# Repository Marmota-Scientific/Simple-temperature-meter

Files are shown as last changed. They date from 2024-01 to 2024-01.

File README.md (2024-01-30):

# Simple temperature meter

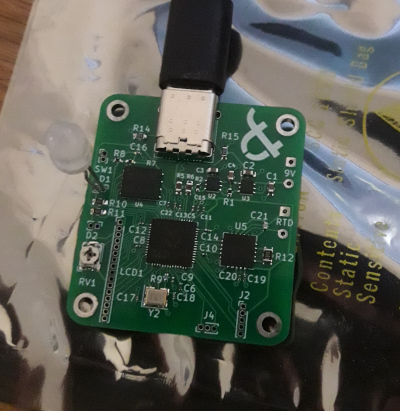
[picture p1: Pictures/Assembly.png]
1st prototype


A simple 15-bit digital temperature meter capable of reading temperatures ranging from –200C to 500C (dependent on reference resistor and used probe). The meter is designed to work with platinum resistance temperature detectors PT100 and PT1000, which are converted into digital values with the usage of a MAX31865 ADC with a nominal temperature resolution of 0.03125C over full range.  

### Connectivity  

- USB 1.1 USB C  

- Handles programming and data output

### User interface

- 2 x 16 character LCD display
- 2 LEDs for user adjustable temperature level alarms  
- Rotary encoder with button  

### Power supply

- Designed to work on a 9V battery
- Operational input voltage level 18V – 5V  
- TPS7A26 linear voltage regulator

### ADC

- MAX31865 15-Bit ADC

### MCU

- RP2040 MCU
- 12 MHz clock speed

## Revision history

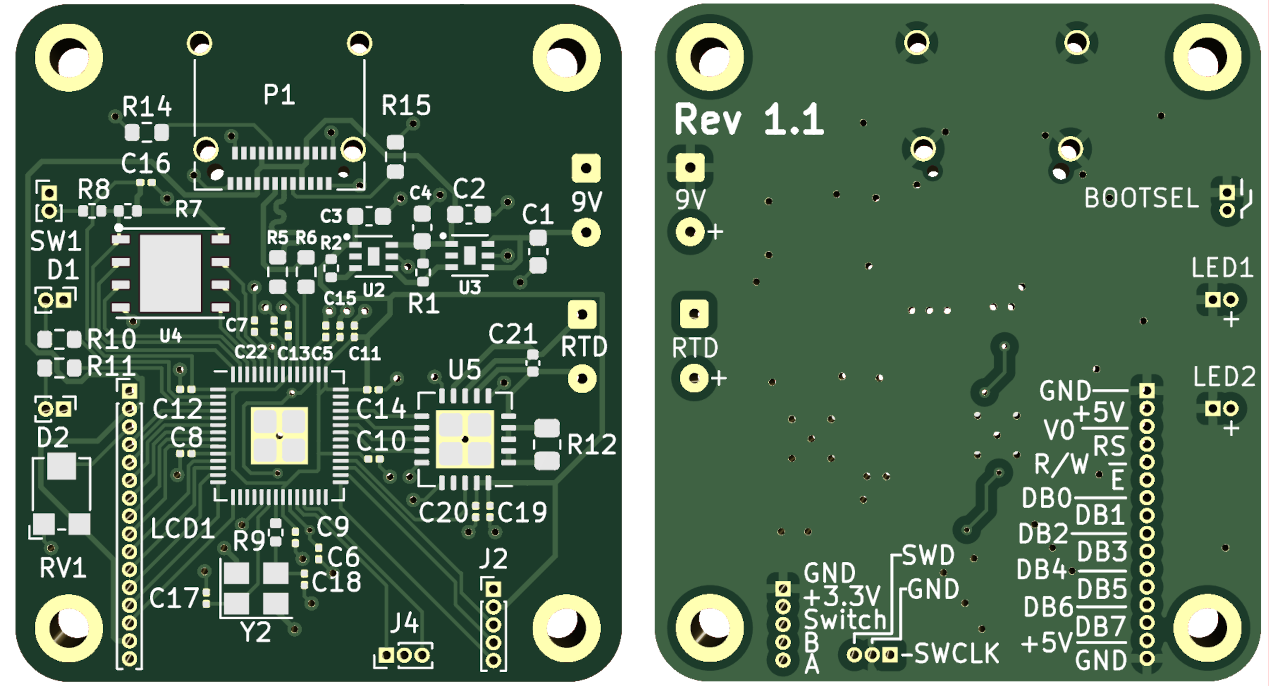
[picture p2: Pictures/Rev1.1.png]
Rev 1.1


- The first working prototype
- Focus on compact sizing over all

### Revision 2.X

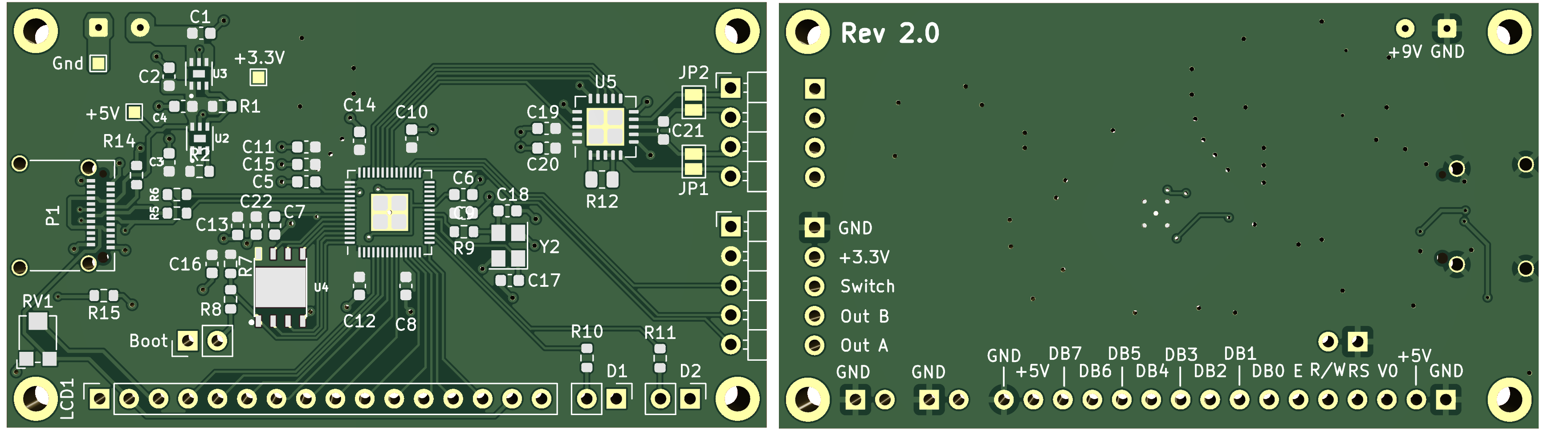
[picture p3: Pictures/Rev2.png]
Rev 2.0


- Focus shifted to ease of construction
- Board dimensions and mounting holes match screen spesification

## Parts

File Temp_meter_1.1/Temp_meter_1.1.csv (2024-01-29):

Id | Designator | Footprint | Quantity | Designation | Supplier and ref
1 | H4,H1,H2,H3 | MountingHole_2.2mm_M2_DIN965_Pad | 4 | MountingHole
2 | C3,C2,C1,C4 | C_0603_1608Metric | 4 | 1µF
3 | C7,C8,C20,C13,C22,C11,C10,C16,C14,C6,C9,C19,C12 | C_0201_0603Metric | 13 | 0.1µF
4 | R5,R6 | R_0603_1608Metric | 2 | 27
5 | R9 | R_0402_1005Metric | 1 | 2k
6 | J2 | PinHeader_1x05_P1.00mm_Vertical | 1 | Rotary encoder
7 | C5,C15 | C_0201_0603Metric | 2 | 1µF
8 | R11,R10 | R_0603_1608Metric | 2 | 330
9 | D1,D2 | PinHeader_1x02_P1.00mm_Vertical | 2 | LED
10 | R14,R15 | R_0603_1608Metric | 2 | 5.1k
11 | R7,R1,R2 | R_0402_1005Metric | 3 | 10k
12 | C17,C18 | C_0201_0603Metric | 2 | 6pF
13 | J1 | SolderWire-0.1sqmm_1x02_P3.6mm_D0.4mm_OD1mm | 1 | 9V in
14 | U5 | TQFN-20-1EP_5x5mm_P0.65mm_EP3.25x3.25mm | 1 | MAX31865xTP
15 | J3 | SolderWire-0.1sqmm_1x02_P3.6mm_D0.4mm_OD1mm | 1 | RTD connector
16 | U4 | SON127P610X510X80-8N430X340 | 1 | W25Q128JVPIQ
17 | LCD1 | PinHeader_1x16_P1.00mm_Vertical | 1 | MC10811A6W
18 | R12 | R_0805_2012Metric | 1 | 1.5k
19 | P1 | USB_C_Receptacle_Amphenol_12401610E4-2A_CircularHoles | 1 | USB_C_Plug_USB2.0
20 | Y2 | Crystal_SMD_3225-4Pin_3.2x2.5mm | 1 | Crystal_GND24
21 | SW1 | PinHeader_1x02_P1.00mm_Vertical | 1 | SW_DIP_x01
22 | U2 | SON65P200X200X80-7N | 1 | TPS7A2633DRVR
23 | R8 | R_0402_1005Metric | 1 | 1k
24 | J4 | PinHeader_1x03_P1.00mm_Vertical | 1 | Debug
25 | U3 | SON65P200X200X80-7N | 1 | TPS7A2650DRVR
26 | C21 | C_0402_1005Metric | 1 | 10nF
27 | RV1 | Potentiometer_Bourns_TC33X_Vertical | 1 | 20k
28 | U1 | QFN-56-1EP_7x7mm_P0.4mm_EP3.2x3.2mm | 1 | RP2040

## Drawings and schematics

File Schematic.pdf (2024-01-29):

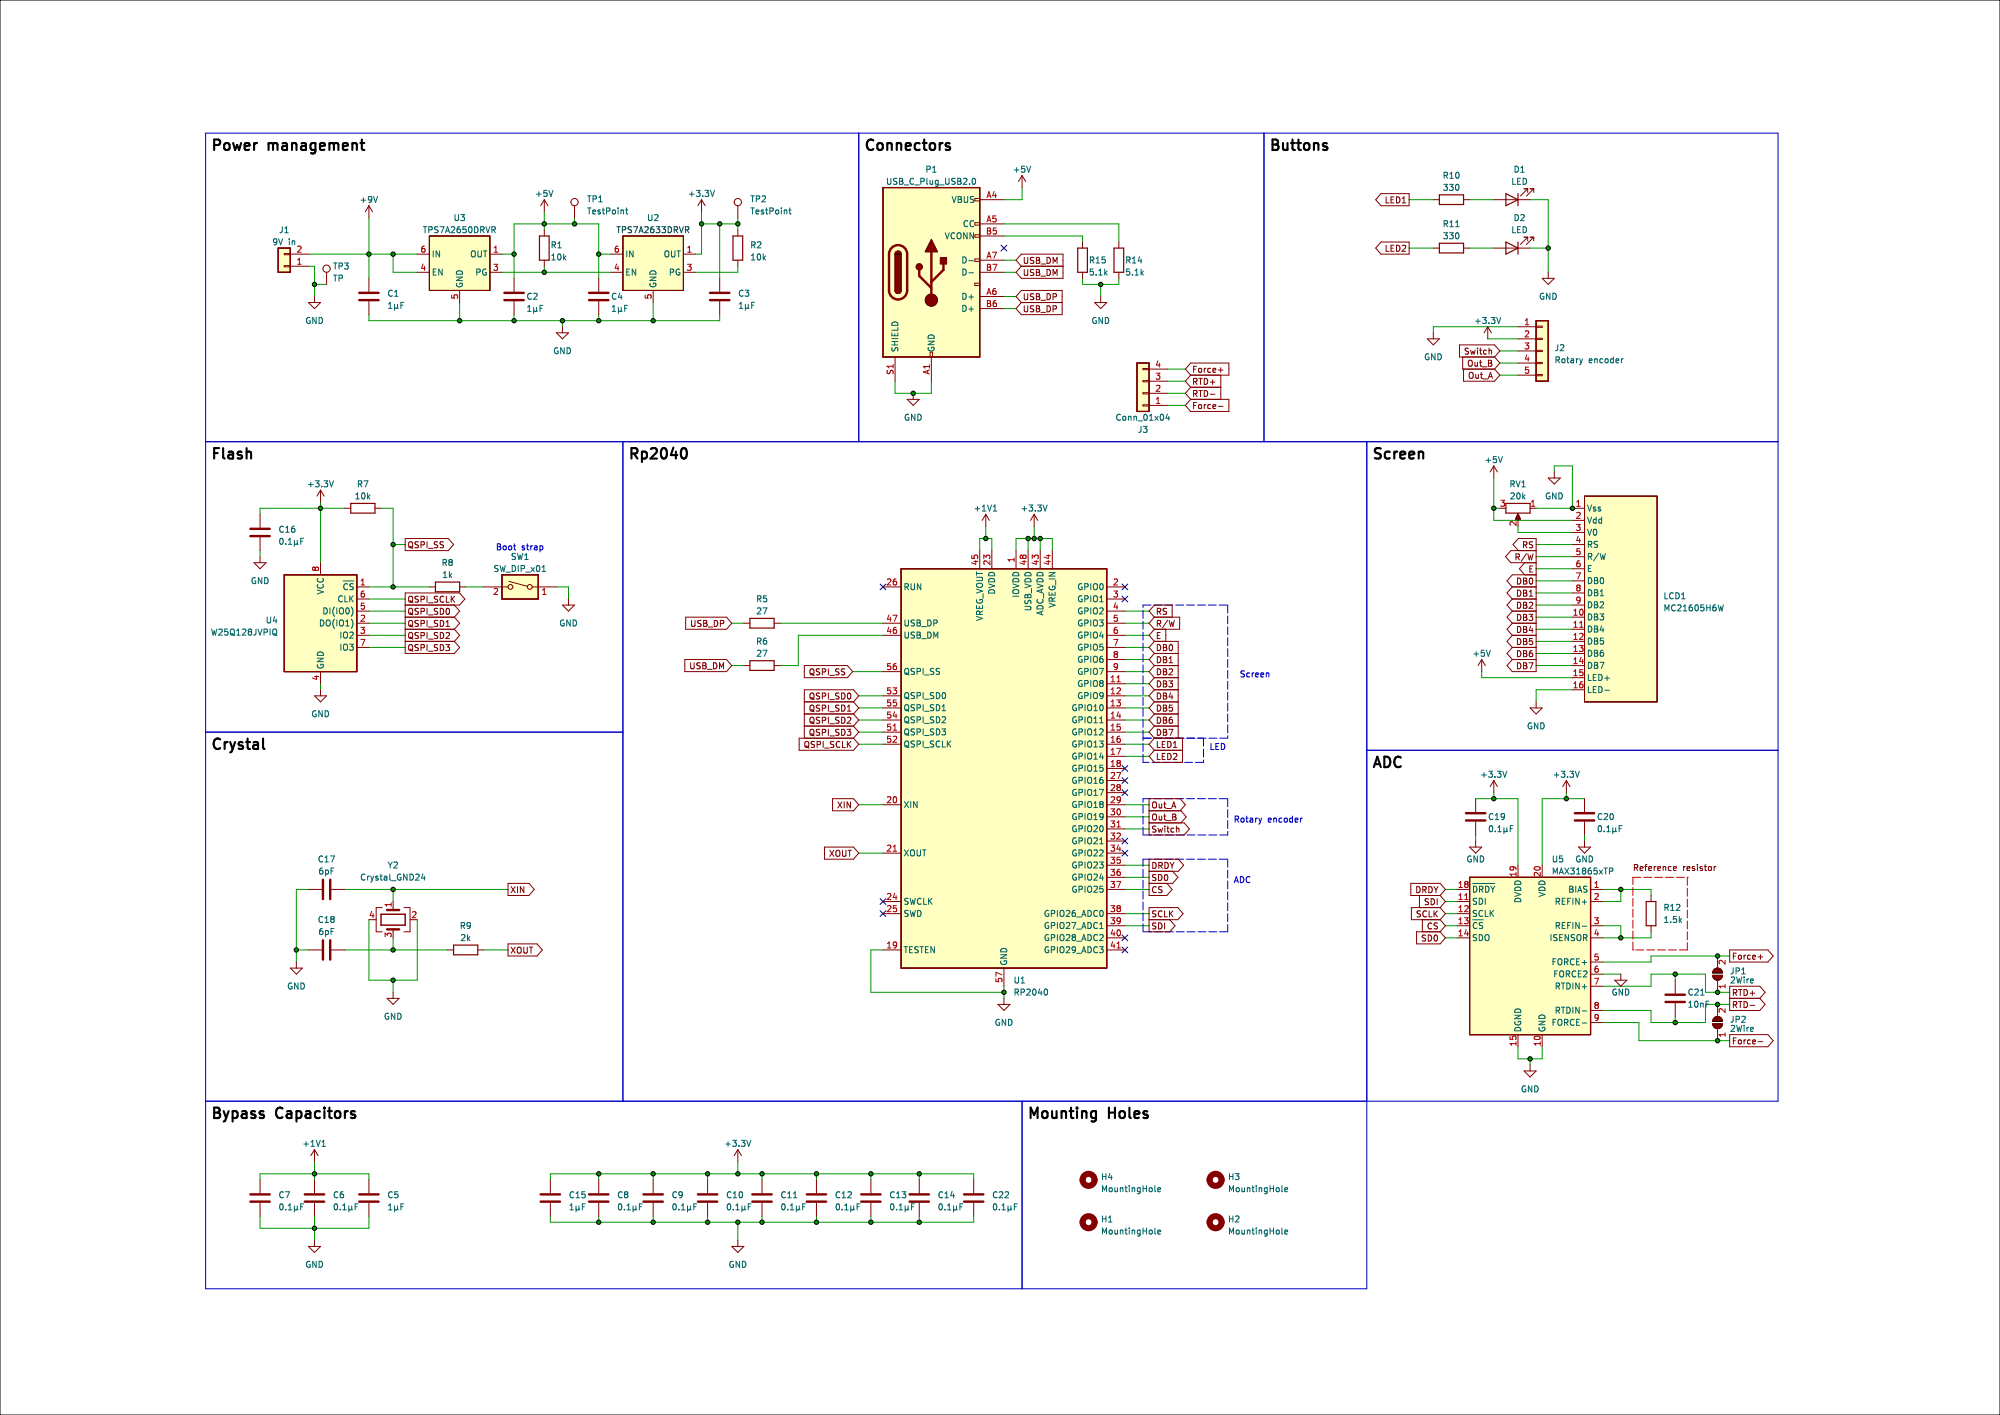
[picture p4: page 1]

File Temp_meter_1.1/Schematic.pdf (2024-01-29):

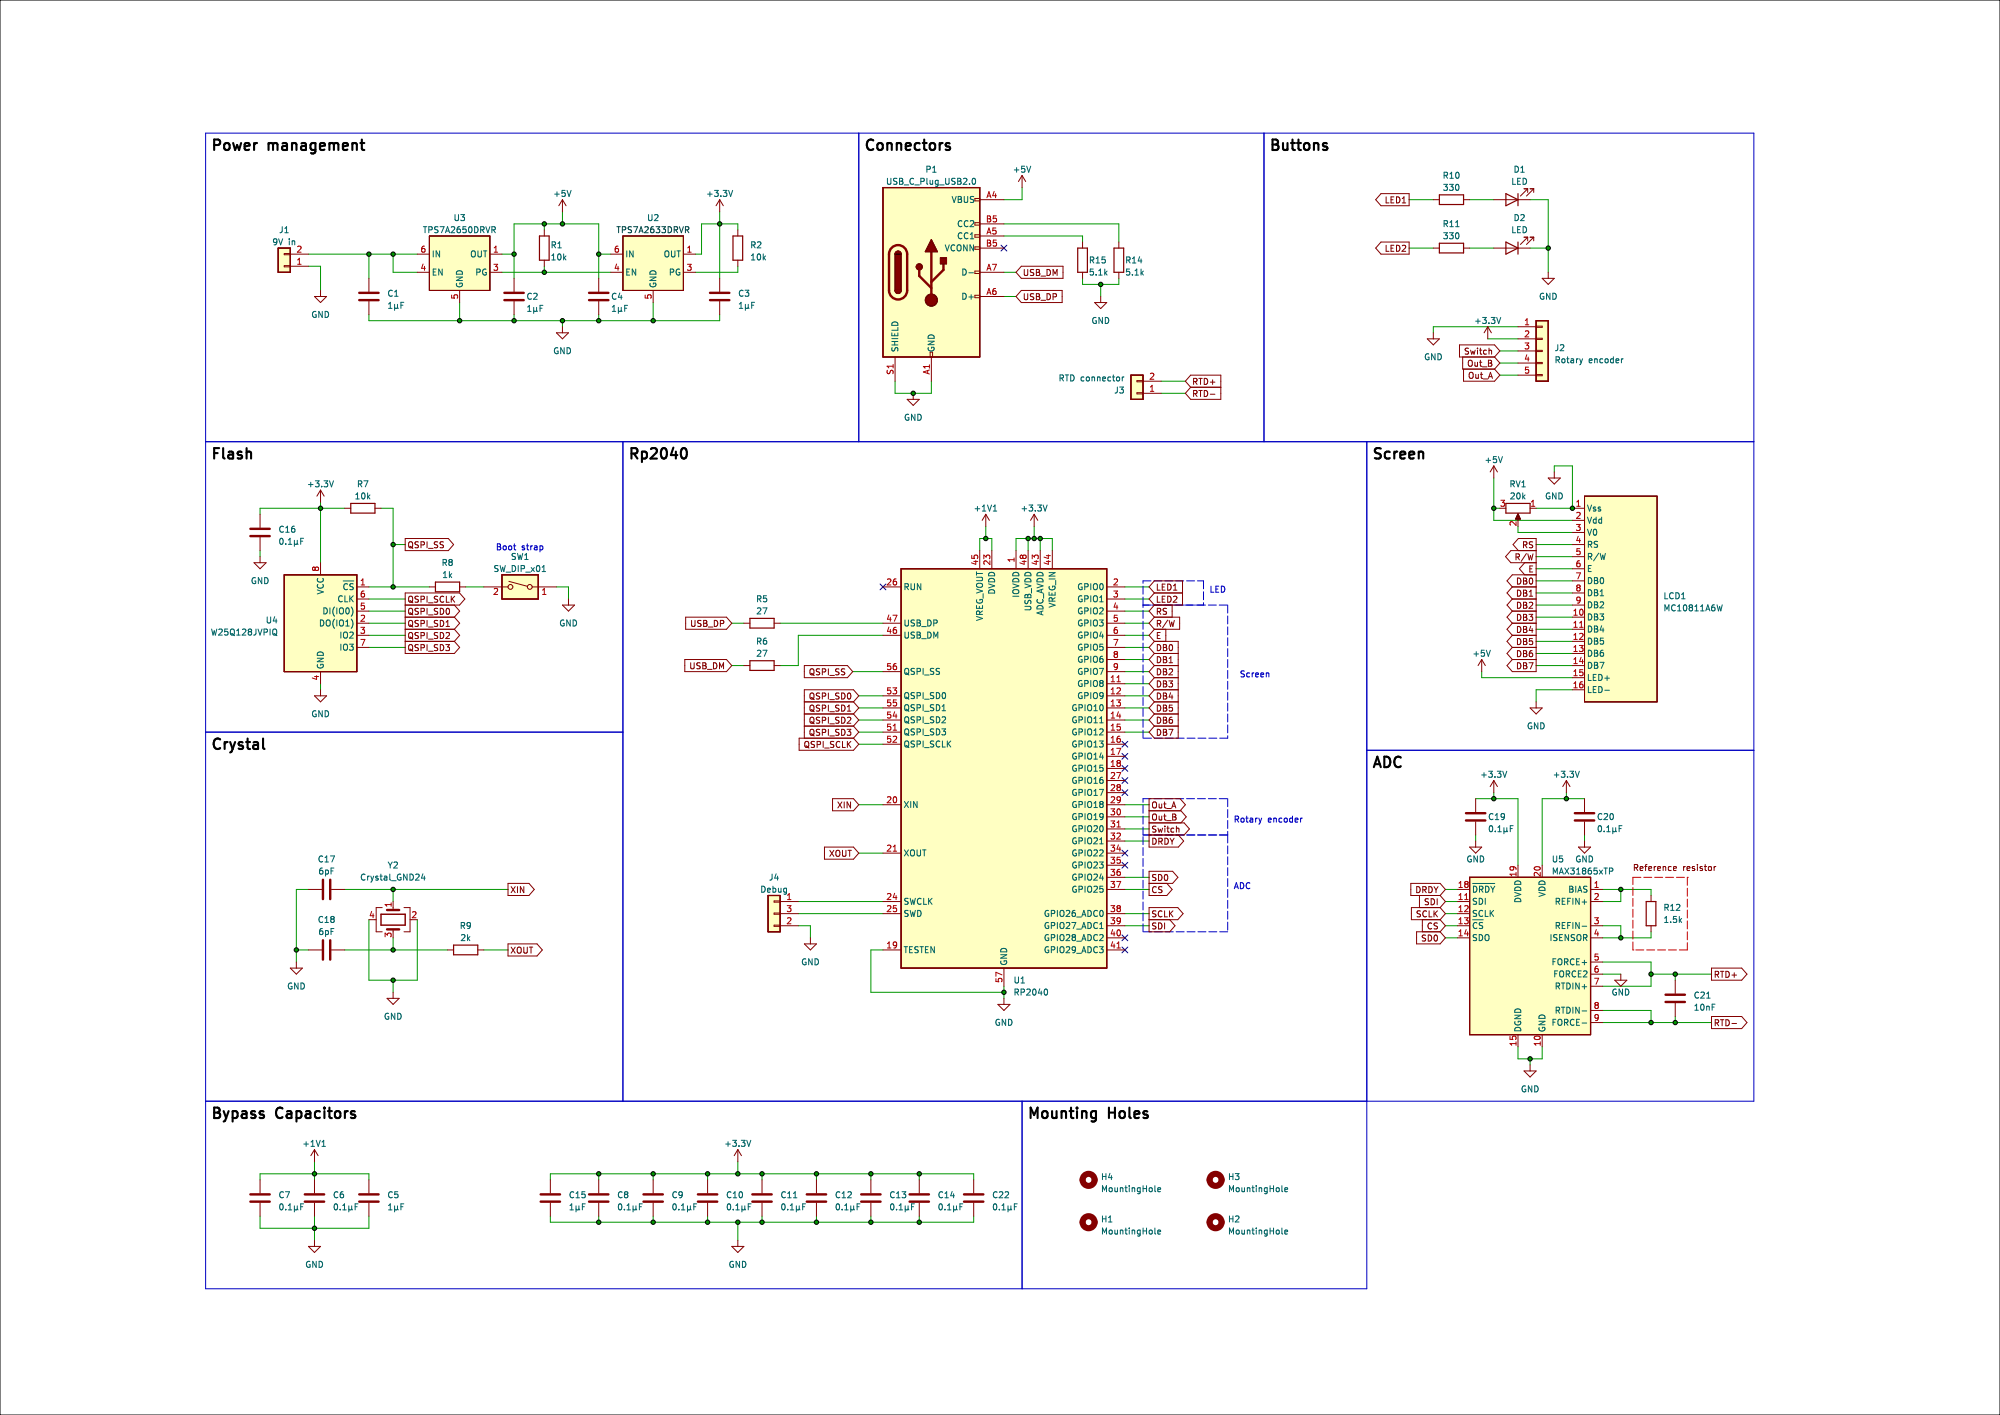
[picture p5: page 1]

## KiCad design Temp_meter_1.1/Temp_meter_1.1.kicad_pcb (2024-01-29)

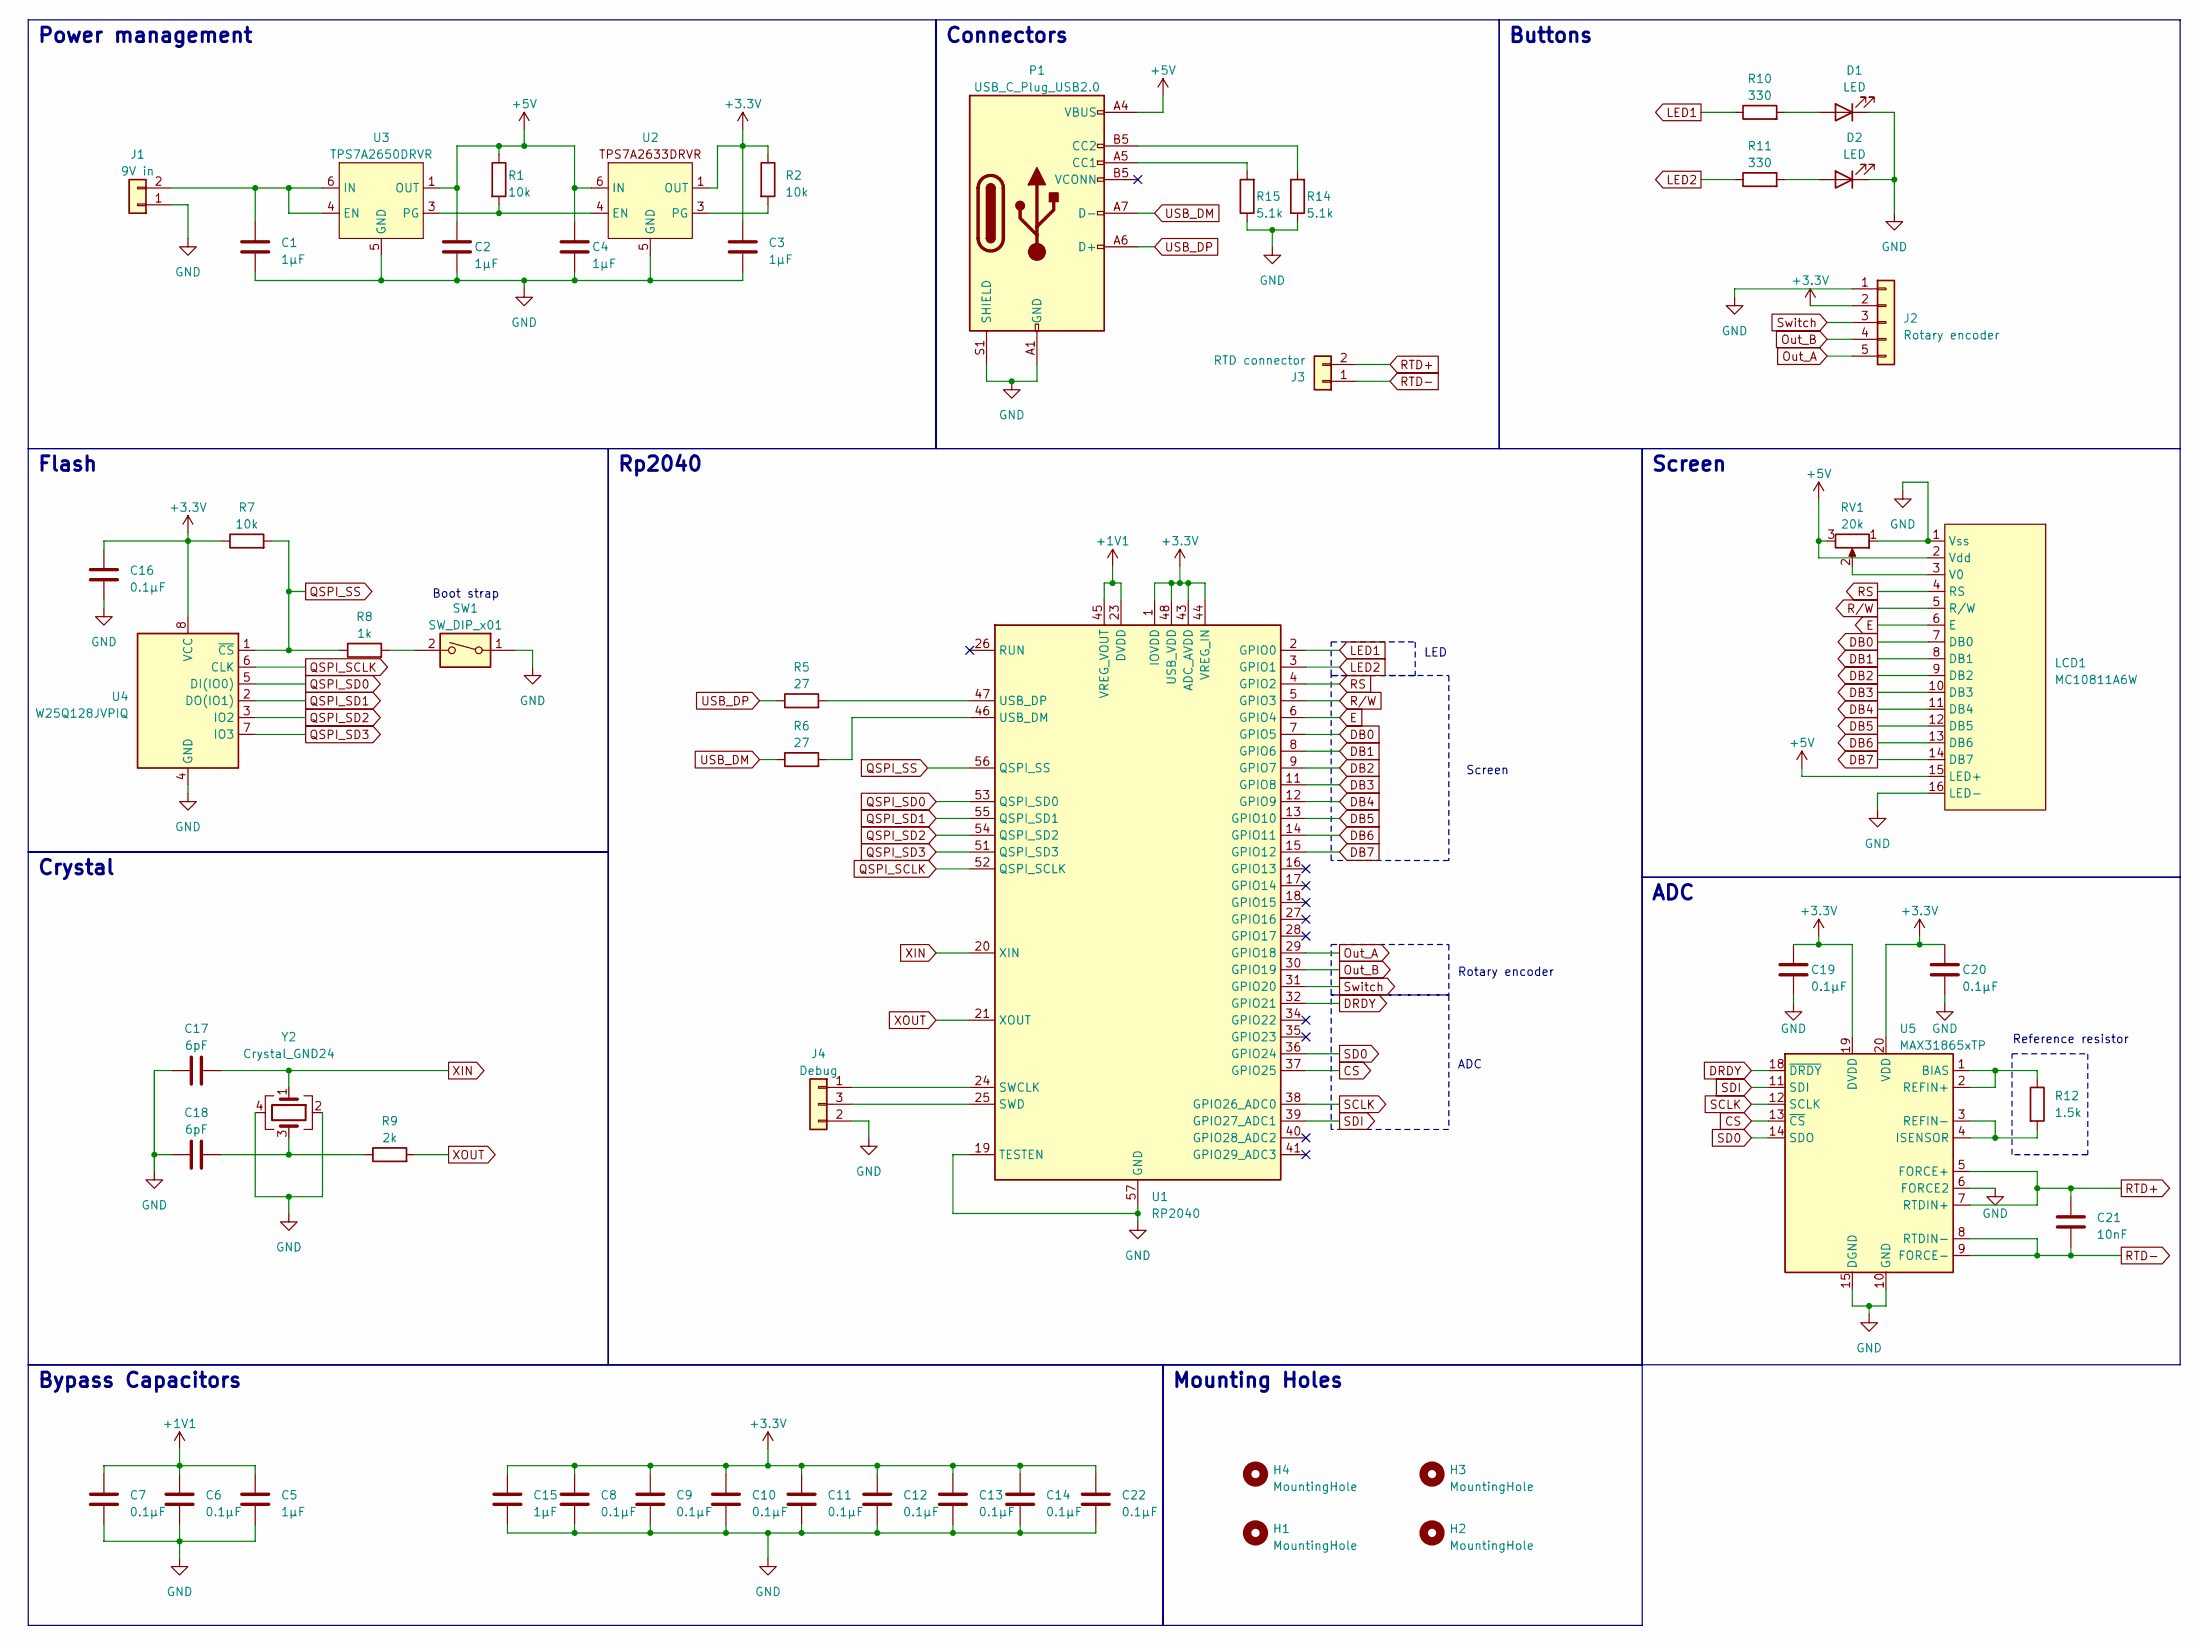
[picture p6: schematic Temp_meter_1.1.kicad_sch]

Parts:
C1, C2, C3, C4: 1µF; C_0603_1608Metric
C5, C15: 1µF; C_0201_0603Metric
C6, C7, C8, C9, C10, C11, C12, C13, C14, C16, C19, C20, C22: 0.1µF; C_0201_0603Metric
C17, C18: 6pF; C_0201_0603Metric
C21: 10nF; C_0402_1005Metric
D1, D2: LED; PinHeader_1x02_P1.00mm_Vertical
H1, H2, H3, H4: MountingHole; MountingHole_2.2mm_M2_DIN965_Pad
J1: 9V in; SolderWire-0.1sqmm_1x02_P3.6mm_D0.4mm_OD1mm
J2: Rotary encoder; PinHeader_1x05_P1.00mm_Vertical
J3: RTD connector; SolderWire-0.1sqmm_1x02_P3.6mm_D0.4mm_OD1mm
J4: Debug; PinHeader_1x03_P1.00mm_Vertical
LCD1: MC10811A6W; PinHeader_1x16_P1.00mm_Vertical
P1: USB_C_Plug_USB2.0; USB_C_Receptacle_Amphenol_12401610E4-2A_CircularHoles
R1, R2, R7: 10k; R_0402_1005Metric
R5, R6: 27; R_0603_1608Metric
R8: 1k; R_0402_1005Metric
R9: 2k; R_0402_1005Metric
R10, R11: 330; R_0603_1608Metric
R12: 1.5k; R_0805_2012Metric
R14, R15: 5.1k; R_0603_1608Metric
RV1: 20k; Potentiometer_Bourns_TC33X_Vertical
SW1: SW_DIP_x01; PinHeader_1x02_P1.00mm_Vertical
U1: RP2040; QFN-56-1EP_7x7mm_P0.4mm_EP3.2x3.2mm
U2: TPS7A2633DRVR; SON65P200X200X80-7N
U3: TPS7A2650DRVR; SON65P200X200X80-7N
U4: W25Q128JVPIQ; SON127P610X510X80-8N430X340
U5: MAX31865xTP; TQFN-20-1EP_5x5mm_P0.65mm_EP3.25x3.25mm
Y2: Crystal_GND24; Crystal_SMD_3225-4Pin_3.2x2.5mm

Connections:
+1V1: C5.1, C6.1, C7.1, U1.23 (DVDD), U1.45 (VREG_VOUT), U1.50 (DVDD)
+3.3V: C3.1, C8.1, C9.1, C10.1, C11.1, C12.1, C13.1, C14.1, C15.1, C16.1, C19.1, C20.1, C22.1, J2.2, R2.1, R7.1, U1.1 (IOVDD), U1.10 (IOVDD), U1.22 (IOVDD), U1.33 (IOVDD), U1.42 (IOVDD), U1.43 (ADC_AVDD), U1.44 (VREG_IN), U1.48 (USB_VDD), U1.49 (IOVDD), U2.1 (OUT), U4.8 (VCC), U5.19 (DVDD), U5.20 (VDD)
+5V: C2.1, C4.1, LCD1.2 (Vdd), LCD1.15 (LED+), P1.A4 (VBUS), P1.A9 (VBUS), P1.B4 (VBUS), P1.B9 (VBUS), R1.1, RV1.3, U2.6 (IN), U3.1 (OUT)
CS: U1.37 (GPIO25), U5.13 (~CS)
DB0: LCD1.7 (DB0), U1.7 (GPIO5)
DB1: LCD1.8 (DB1), U1.8 (GPIO6)
DB2: LCD1.9 (DB2), U1.9 (GPIO7)
DB3: LCD1.10 (DB3), U1.11 (GPIO8)
DB4: LCD1.11 (DB4), U1.12 (GPIO9)
DB5: LCD1.12 (DB5), U1.13 (GPIO10)
DB6: LCD1.13 (DB6), U1.14 (GPIO11)
DB7: LCD1.14 (DB7), U1.15 (GPIO12)
DRDY: U1.32 (GPIO21), U5.18 (~DRDY)
E: LCD1.6 (E), U1.6 (GPIO4)
GND: C1.2, C2.2, C3.2, C4.2, C5.2, C6.2, C7.2, C8.2, C9.2, C10.2, C11.2, C12.2, C13.2, C14.2, C15.2, C16.2, C17.1, C18.1, C19.2, C20.2, C22.2, D1.1 (K), D2.1 (K), J1.1, J2.1, J4.2, LCD1.1 (Vss), LCD1.16 (LED-), P1.A1 (GND), P1.A12 (GND), P1.B1 (GND), P1.B12 (GND), P1.S1 (SHIELD), R14.1, R15.1, RV1.1, SW1.1, U1.19 (TESTEN), U1.57 (GND), U2.5 (GND), U3.5 (GND), U4.4 (GND), U5.6 (FORCE2), U5.10 (GND), U5.15 (DGND), U5.16 (GND), U5.21 (GND), Y2.2, Y2.4
LED1: R10.1, U1.2 (GPIO0)
LED2: R11.1, U1.3 (GPIO1)
unnamed: C18.2, R9.1, Y2.3
unnamed: D1.2 (A), R10.2
unnamed: D2.2 (A), R11.2
unnamed: C1.1, J1.2, U3.4 (EN), U3.6 (IN)
unnamed: J4.1, U1.24 (SWCLK)
unnamed: J4.3, U1.25 (SWD)
unnamed: LCD1.3 (V0), RV1.2
unnamed: P1.A5 (CC1), R15.2
unnamed: P1.B5 (CC2), R14.2
unnamed: R8.2, SW1.2
unnamed: R6.2, U1.46 (USB_DM)
unnamed: R5.2, U1.47 (USB_DP)
unnamed: R1.2, U2.4 (EN), U3.3 (PG)
unnamed: R2.2, U2.3 (PG)
unnamed: R12.1, U5.1 (BIAS), U5.2 (REFIN+)
unnamed: R12.2, U5.3 (REFIN-), U5.4 (ISENSOR)
Out_A: J2.5, U1.29 (GPIO18)
Out_B: J2.4, U1.30 (GPIO19)
QSPI_SCLK: U1.52 (QSPI_SCLK), U4.6 (CLK)
QSPI_SD0: U1.53 (QSPI_SD0), U4.5 (DI(IO0))
QSPI_SD1: U1.55 (QSPI_SD1), U4.2 (DO(IO1))
QSPI_SD2: U1.54 (QSPI_SD2), U4.3 (IO2)
QSPI_SD3: U1.51 (QSPI_SD3), U4.7 (IO3)
QSPI_SS: R7.2, R8.1, U1.56 (QSPI_SS), U4.1 (~CS)
RS: LCD1.4 (RS), U1.4 (GPIO2)
RTD+: C21.1, J3.2, U5.5 (FORCE+), U5.7 (RTDIN+)
RTD-: C21.2, J3.1, U5.8 (RTDIN-), U5.9 (FORCE-)
R/W: LCD1.5 (R/W), U1.5 (GPIO3)
SCLK: U1.38 (GPIO26_ADC0), U5.12 (SCLK)
SD0: U1.36 (GPIO24), U5.14 (SDO)
SDI: U1.39 (GPIO27_ADC1), U5.11 (SDI)
Switch: J2.3, U1.31 (GPIO20)
USB_DM: P1.A7 (D-), R6.1
USB_DP: P1.A6 (D+), R5.1
XIN: C17.2, U1.20 (XIN), Y2.1
XOUT: R9.2, U1.21 (XOUT)

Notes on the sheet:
Rotary encoder
Buttons
Screen
Reference resistor
Bypass Capacitors
Mounting Holes
Flash
Connectors
Rp2040
Boot strap
Power management
LED
ADC
Crystal

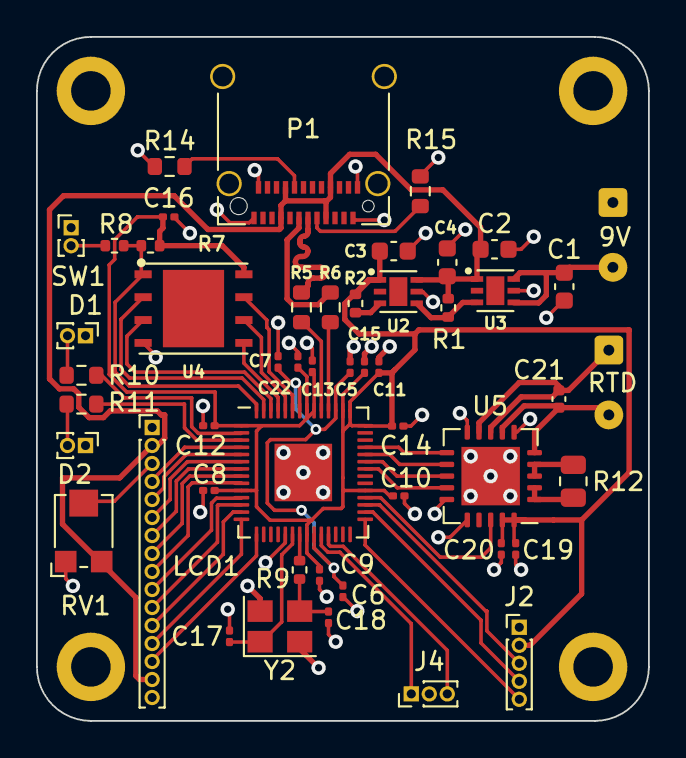
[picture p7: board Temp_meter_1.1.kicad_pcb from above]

Board: 2 copper layers, 34.0 x 38.0 mm, 54 parts (0 on the bottom side), 53 nets.
